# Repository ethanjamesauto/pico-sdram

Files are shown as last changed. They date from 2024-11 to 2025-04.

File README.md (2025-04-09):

# pico-sdram

This project attempts to interface a Raspberry Pi Pico with a [32MB SDRAM IC](https://www.winbond.com/resource-files/w9825g6kh_a04.pdf).

<p>
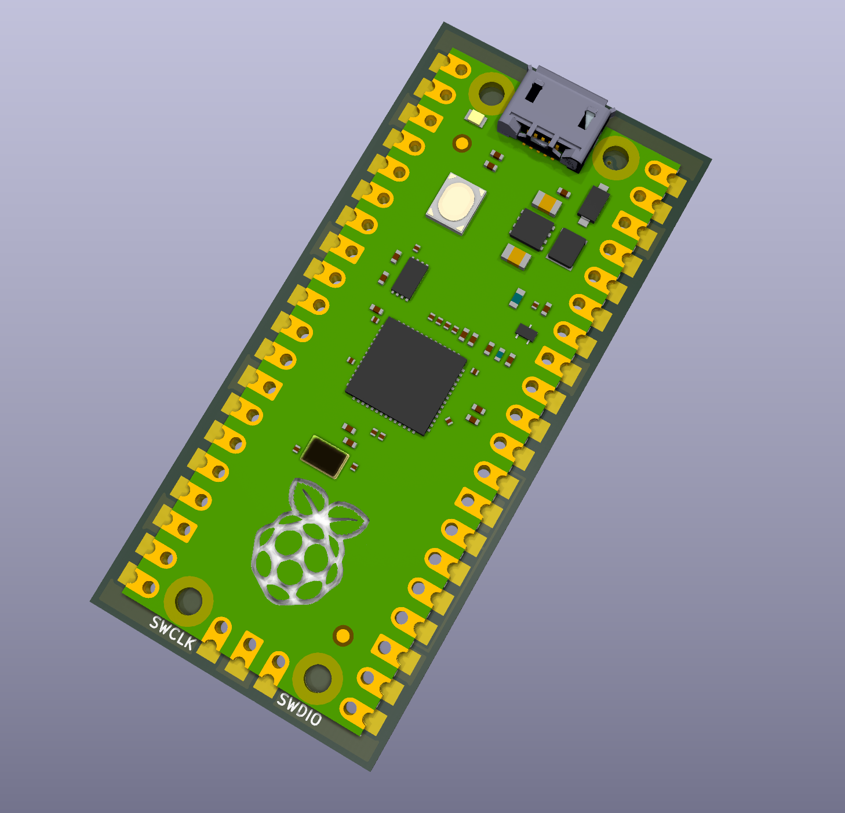
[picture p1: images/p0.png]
  
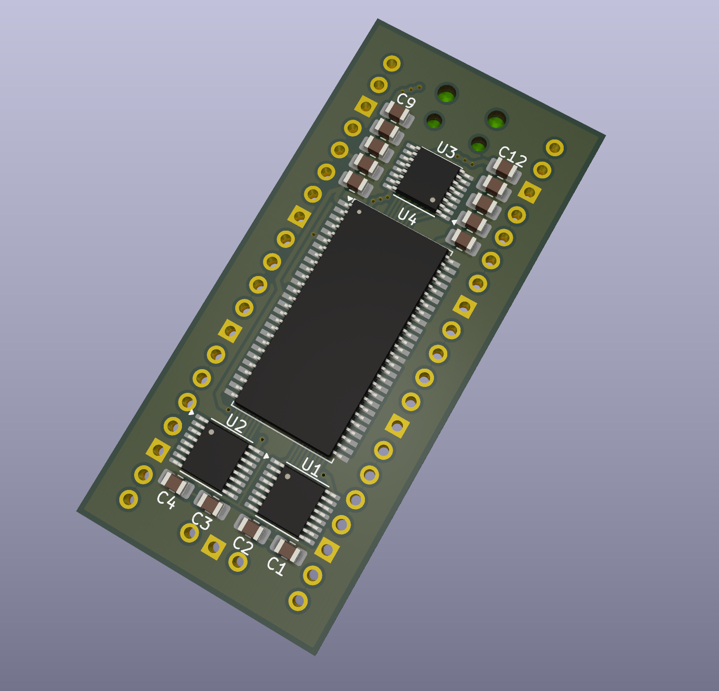
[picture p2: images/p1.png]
   
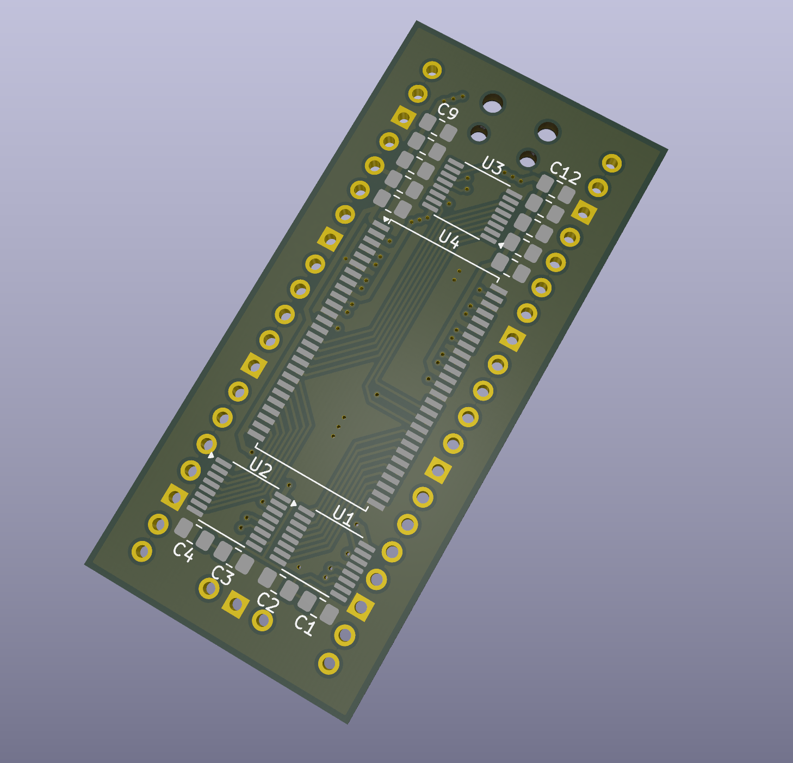
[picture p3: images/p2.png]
  
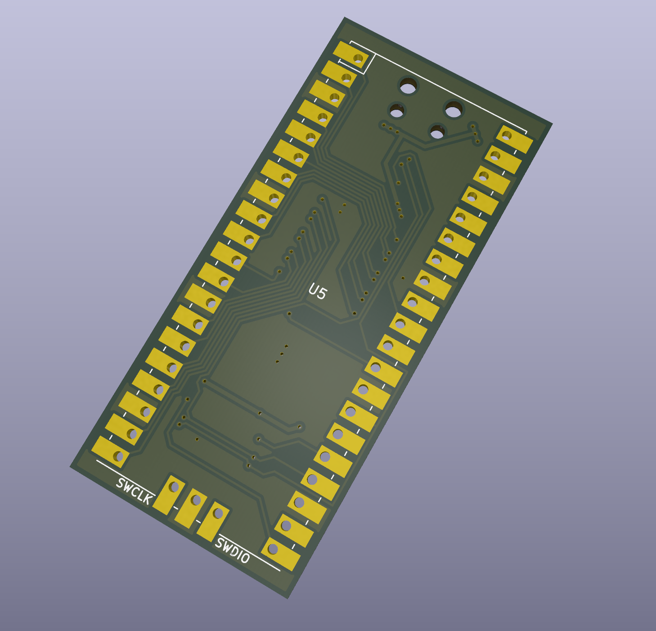
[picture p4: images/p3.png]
  
</p>

## UPDATE - Current State
I have been able to successfully perform single and burst read/writes to the W9825G6KH SDRAM IC. I am running the SDRAM at half the speed of the rp2040 clock - the PIO state machines
are running at the minimum clock divider value.
I don't have full documentation, but some is available in:
* [pico/src/sdram_cmd.c](pico/src/sdram_cmd.c) - contains the main driver code
* [pico/src/pico-sdram.c](pico/src/pico-sdram.c) - example usage of the driver code
* [pico/src/three_74hc595.pio](pico/src/three_74hc595.pio) - PIO driver for the 3x 74hc595 shift registers used to drive the address bus
* [pico/src/data_bus.pio](pico/src/data_bus.pio) - PIO driver for the 16-bit data bus

## Introduction
SDRAM ICs are commonly available in sizes of up to 256MBit (32MB), and most have either an 8-bit or 16-bit data bus width. The control interface uses a total of 23 pins, so there are simply too many pins for an RP2040 to directly drive using GPIOs. 

Shift registers may be reduce the number of GPIOs needed to interface with the ram. Because the RP2040 can only drive shift registers so quickly, the SDRAM chip would need to be driven at a lower clock speed. I propose a solution in which the control pins are driven using shift registers while the data bus is connected directly to the RP2040's GPIOs. This reduces the speed at which commands can be sent to the SDRAM, while still allowing the data bus to run at full speed. This solution has a drawback - it takes more time to send the two commands needed to initiate a read (row activate and read). However, this issue becomes neglible when most reads and writes use large block sizes (for example, when performing 1KB block reads and writes).

## Future Work
Eventually, I'd like to use this SDRAM interface with a PIO-based QSPI interface. The QSPI interface may then appear as a QSPI PSRAM and can be connected to the rp2350's QSPI bus. The pico can then translate "psram" accesses to sdram accesses, which would **allow the pico to natively access sdram in the address space**. This might not be possible.

## Digilent Waveforms SDRAM Protocol Decoder
```js
// rgData: input, raw digital data array
// rgValue: output, decoded data array
// rgFlag: output, decoded flag array

c = rgData.length

for(var i = 0; i < c; i++){
   // take 4 least significant bits
   rgValue[i] = rgData[i] & 0xFF;
   // set flag other than zero for valid data
   rgFlag[i] = 1;
}

// value: value sample
// flag: flag sample
function Value2Text(flag, value) {
  var lower = value & 0xf;
  var addr10 = ((value >> 7) & 1) > 0;
  if (lower & 1) return "";
  if (lower == 14) return "NOP";
  if (lower == 6) return "BURST_TERM";
  if (lower == 10) return addr10 ? "READ_PRECHARGE" : "READ";
  if (lower == 2) return addr10 ? "WRITE_PRECHARGE" : "WRITE";
  if (lower == 12) return "ACTIVATE";
  if (lower == 4) return "PRECHARGE";
  if (lower == 8) return "AUTO_REFRESH";
  if (lower == 0) return "LOAD_MODE";
  return "X";
}
Value2Text(0,0x82)

function Value2Text(flag, value) {
  var lower = value & 0xf;
  var addr10 = ((value >> 7) & 1) > 0;
  if (lower & 1) return "";
  if (lower == 14) return "NOP";
  if (lower == 6) return "BURST_T";
  if (lower == 10) return addr10 ? "READ_P" : "READ";
  if (lower == 2) return addr10 ? "WRITE_P" : "WRITE";
  if (lower == 12) return "ACTIVATE";
  if (lower == 4) return "PRCHG";
  if (lower == 8) return "A_RFRSH";
  if (lower == 0) return "MODE";
  return "X";
}
```

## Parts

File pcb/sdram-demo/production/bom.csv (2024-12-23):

Designator | Footprint | Quantity | Value | LCSC Part #
C1, C4 | 0805 | 2 | 2.2u
C2, C3 | 0805 | 2 | 100n
JP1 | SolderJumper-2_P1.3mm_Open_Pad1.0x1.5mm | 1 | Jumper_2_Open
U1, U2, U3 | SOIC-16_3.9x9.9mm_P1.27mm | 3 | 74HC595
U4 | TSOP-II-54_22.2x10.16mm_P0.8mm | 1 | MT48LC16M16A2P
U5 | RPi_Pico_SMD_TH | 1 | Pico

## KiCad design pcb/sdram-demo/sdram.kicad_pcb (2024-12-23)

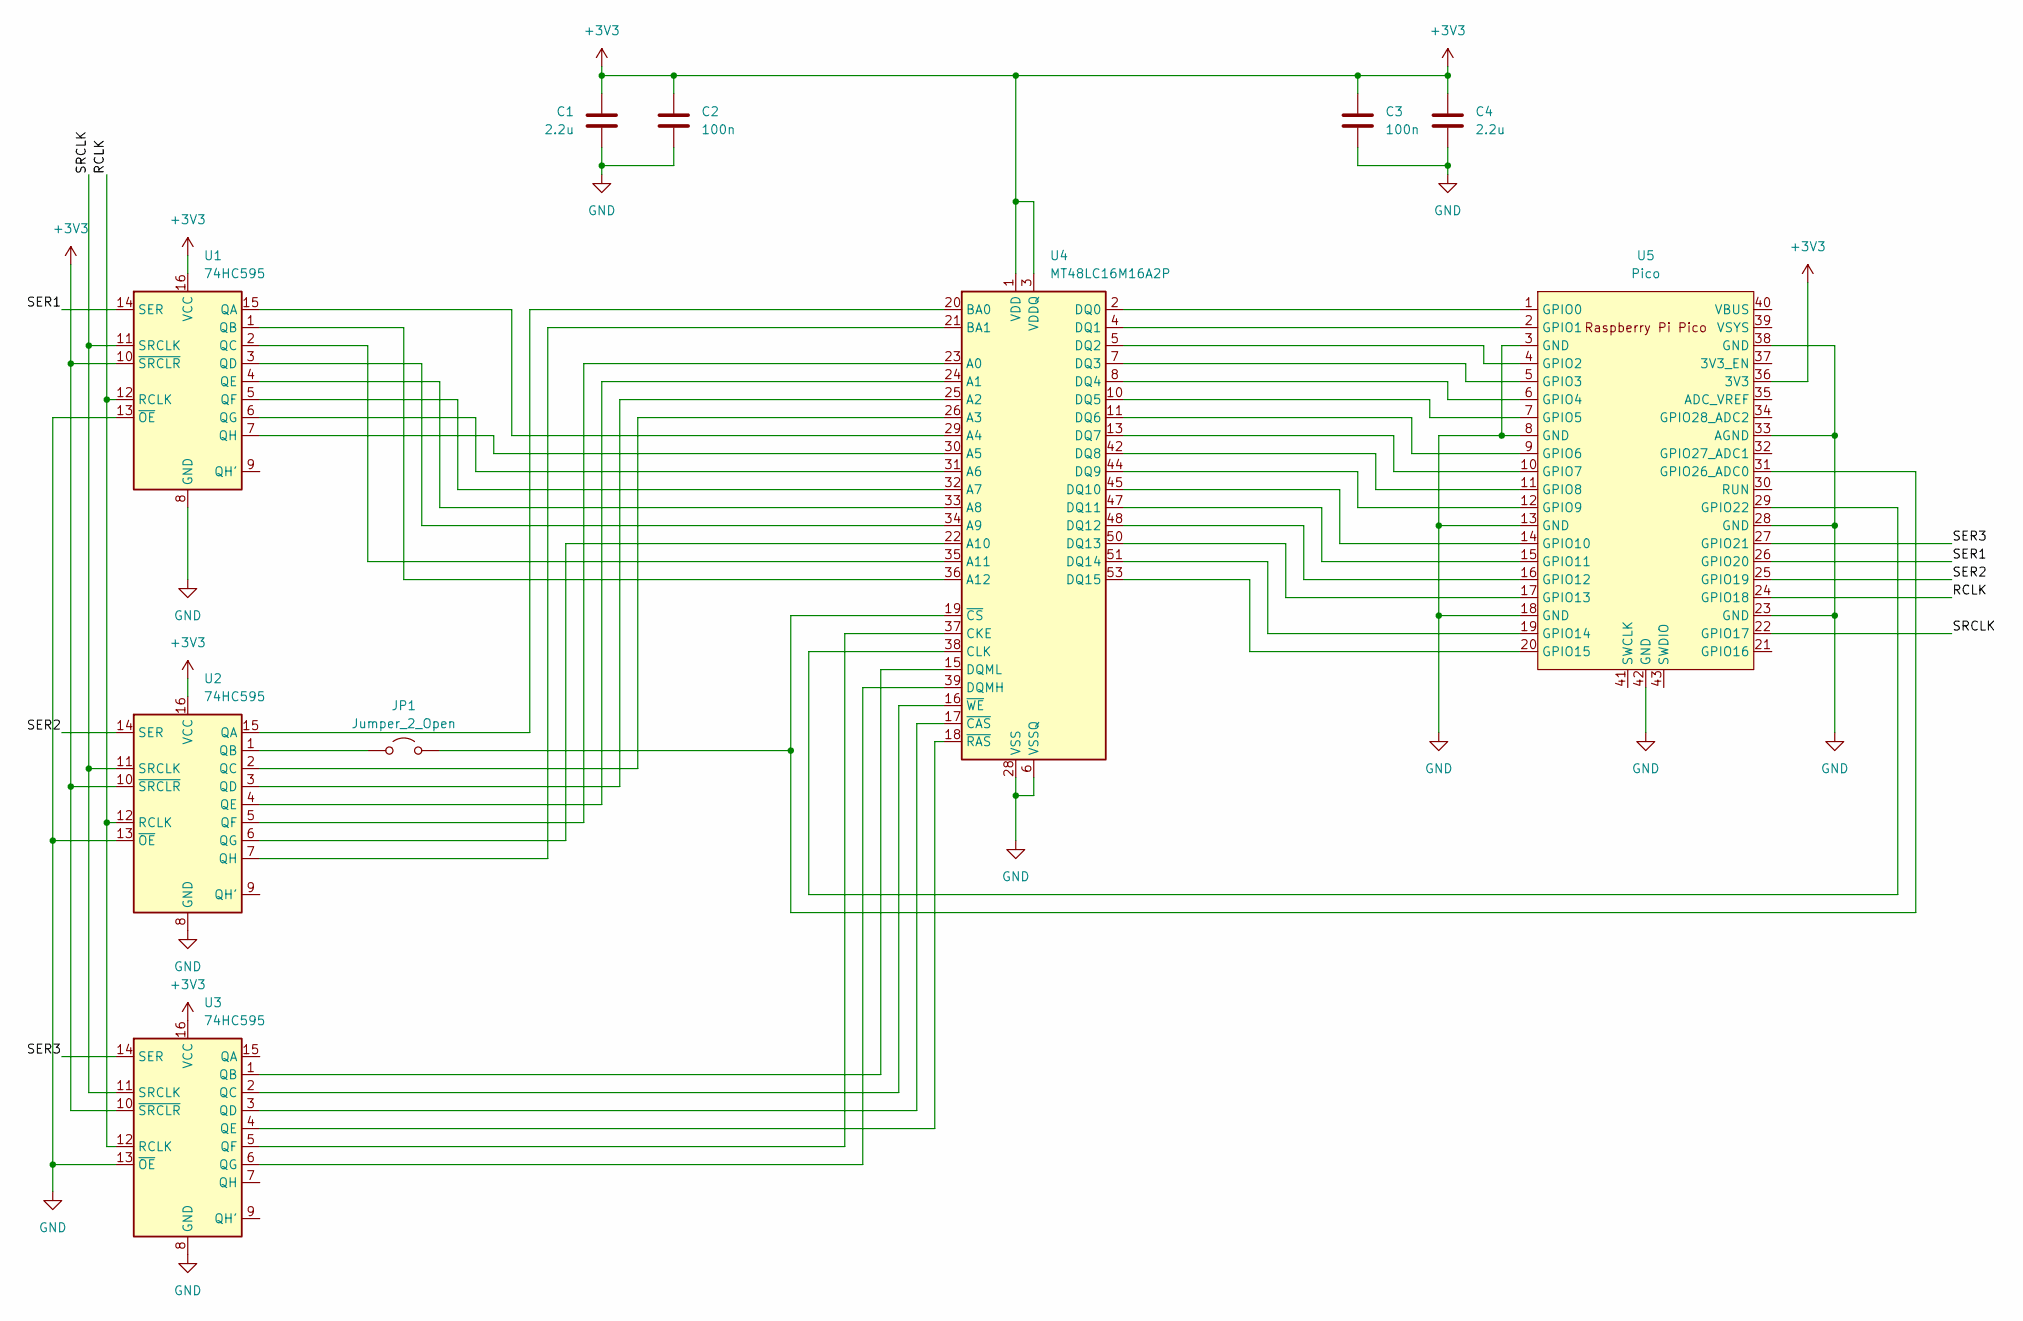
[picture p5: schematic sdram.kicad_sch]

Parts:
C1, C4: 2.2u; C_0805_2012Metric_Pad1.18x1.45mm_HandSolder
C2, C3: 100n; C_0805_2012Metric_Pad1.18x1.45mm_HandSolder
JP1: Jumper_2_Open; SolderJumper-2_P1.3mm_Open_Pad1.0x1.5mm
U1, U2, U3: 74HC595; SOIC-16_3.9x9.9mm_P1.27mm
U4: MT48LC16M16A2P; TSOP-II-54_22.2x10.16mm_P0.8mm
U5: Pico; RPi_Pico_SMD_TH

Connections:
+3V3: C1.1, C2.1, C3.1, C4.1, U1.10 (~SRCLR), U1.16 (VCC), U2.10 (~SRCLR), U2.16 (VCC), U3.10 (~SRCLR), U3.16 (VCC), U4.1 (VDD), U4.3 (VDDQ), U4.9 (VDDQ), U4.14 (VDD), U4.27 (VDD), U4.43 (VDDQ), U4.49 (VDDQ), U5.36 (3V3)
/RCLK: U1.12 (RCLK), U2.12 (RCLK), U3.12 (RCLK), U5.24 (GPIO18)
/SER1: U1.14 (SER), U5.26 (GPIO20)
/SER2: U2.14 (SER), U5.25 (GPIO19)
/SER3: U3.14 (SER), U5.27 (GPIO21)
/SRCLK: U1.11 (SRCLK), U2.11 (SRCLK), U3.11 (SRCLK), U5.22 (GPIO17)
GND: C1.2, C2.2, C3.2, C4.2, U1.8 (GND), U1.13 (~OE), U2.8 (GND), U2.13 (~OE), U3.8 (GND), U3.13 (~OE), U4.6 (VSSQ), U4.12 (VSSQ), U4.28 (VSS), U4.41 (VSS), U4.46 (VSSQ), U4.52 (VSSQ), U4.54 (VSS), U5.3 (GND), U5.8 (GND), U5.13 (GND), U5.18 (GND), U5.23 (GND), U5.28 (GND), U5.33 (AGND), U5.38 (GND), U5.42 (GND)
unnamed: JP1.1 (A), U2.1 (QB)
unnamed: JP1.2 (B), U4.19 (~CS), U5.31 (GPIO26_ADC0)
unnamed: U1.15 (QA), U4.29 (A4)
unnamed: U1.1 (QB), U4.36 (A12)
unnamed: U1.2 (QC), U4.35 (A11)
unnamed: U1.3 (QD), U4.34 (A9)
unnamed: U1.4 (QE), U4.33 (A8)
unnamed: U1.5 (QF), U4.32 (A7)
unnamed: U1.6 (QG), U4.31 (A6)
unnamed: U1.7 (QH), U4.30 (A5)
unnamed: U2.15 (QA), U4.20 (BA0)
unnamed: U2.2 (QC), U4.26 (A3)
unnamed: U2.3 (QD), U4.25 (A2)
unnamed: U2.4 (QE), U4.24 (A1)
unnamed: U2.5 (QF), U4.23 (A0)
unnamed: U2.6 (QG), U4.22 (A10)
unnamed: U2.7 (QH), U4.21 (BA1)
unnamed: U3.1 (QB), U4.15 (DQML)
unnamed: U3.2 (QC), U4.16 (~WE)
unnamed: U3.3 (QD), U4.17 (~CAS)
unnamed: U3.4 (QE), U4.18 (~RAS)
unnamed: U3.5 (QF), U4.37 (CKE)
unnamed: U3.6 (QG), U4.39 (DQMH)
unnamed: U4.38 (CLK), U5.29 (GPIO22)
unnamed: U4.2 (DQ0), U5.1 (GPIO0)
unnamed: U4.4 (DQ1), U5.2 (GPIO1)
unnamed: U4.5 (DQ2), U5.4 (GPIO2)
unnamed: U4.7 (DQ3), U5.5 (GPIO3)
unnamed: U4.8 (DQ4), U5.6 (GPIO4)
unnamed: U4.10 (DQ5), U5.7 (GPIO5)
unnamed: U4.11 (DQ6), U5.9 (GPIO6)
unnamed: U4.13 (DQ7), U5.10 (GPIO7)
unnamed: U4.42 (DQ8), U5.11 (GPIO8)
unnamed: U4.44 (DQ9), U5.12 (GPIO9)
unnamed: U4.45 (DQ10), U5.14 (GPIO10)
unnamed: U4.47 (DQ11), U5.15 (GPIO11)
unnamed: U4.48 (DQ12), U5.16 (GPIO12)
unnamed: U4.50 (DQ13), U5.17 (GPIO13)
unnamed: U4.51 (DQ14), U5.19 (GPIO14)
unnamed: U4.53 (DQ15), U5.20 (GPIO15)

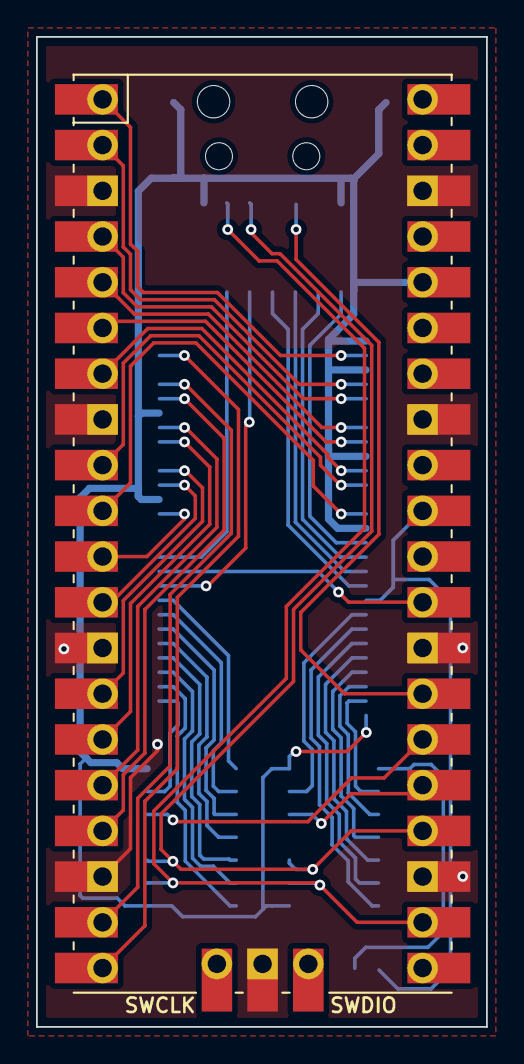
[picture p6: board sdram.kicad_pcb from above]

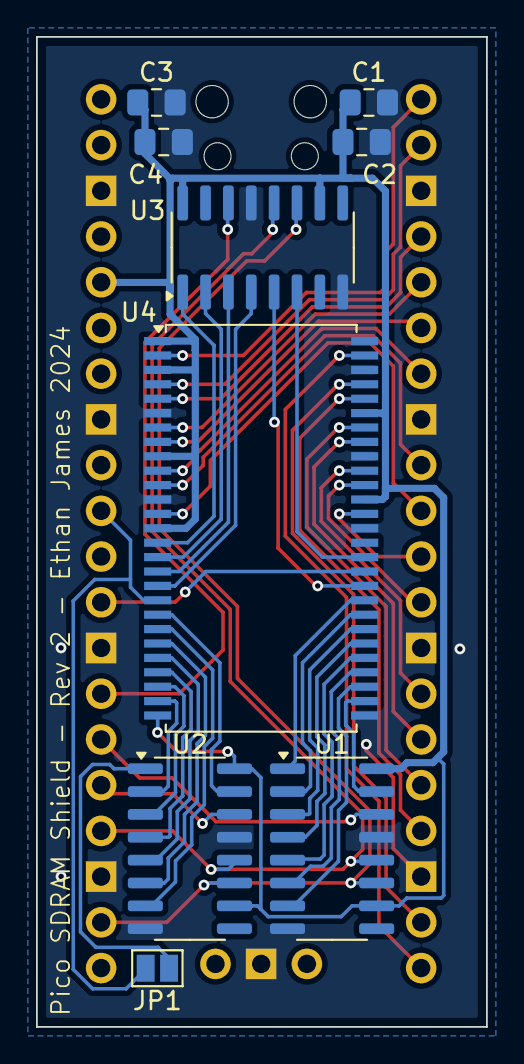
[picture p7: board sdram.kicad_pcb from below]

Board: 2 copper layers, 25.0 x 55.0 mm, 10 parts (9 on the bottom side), 47 nets.

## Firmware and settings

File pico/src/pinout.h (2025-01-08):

// #define CONFIG_DEBUG
// #define CONFIG_REV1
#define CONFIG_REV2

// On rev 2.0, the CS pin is also connected to this gpio.
// Right now, I'm using the CS pin on the shift register, so this pin should be set to high impedance.
#define SDRAM_CS 26


#ifdef CONFIG_DEBUG

// shift register 1
#define PIN_SDRAM_CS (1 << 0*3)
#define PIN_SDRAM_RAS (1 << 1*3)
#define PIN_SDRAM_CAS (1 << 2*3)
#define PIN_SDRAM_WE (1 << 3*3)
#define PIN_SDRAM_CKE (1 << 4*3)
#define PIN_SDRAM_DQML (1 << 5*3)
#define PIN_SDRAM_DQMH (1 << 6*3)
#define PIN_SDRAM_ADDR10 (1 << 7*3)

// shift register 2
#define PIN_SDRAM_ADDR8 (2 << 0*3)
#define PIN_SDRAM_ADDR9 (2 << 1*3)
// #define PIN_SDRAM_ADDR10 (2 << 2*3)
#define PIN_SDRAM_ADDR11 (2 << 3*3)
#define PIN_SDRAM_ADDR12 (2 << 4*3)
#define PIN_SDRAM_BA0 (2 << 5*3)
#define PIN_SDRAM_BA1 (2 << 6*3)

// shift register 3
#define PIN_SDRAM_ADDR0 (4 << 0*3)
#define PIN_SDRAM_ADDR1 (4 << 1*3)
#define PIN_SDRAM_ADDR2 (4 << 2*3)
#define PIN_SDRAM_ADDR3 (4 << 3*3)
#define PIN_SDRAM_ADDR4 (4 << 4*3)
#define PIN_SDRAM_ADDR5 (4 << 5*3)
#define PIN_SDRAM_ADDR6 (4 << 6*3)
#define PIN_SDRAM_ADDR7 (4 << 7*3)



#define DATA_BASE 0
#define DATA_WIDTH 16

#define CMD_SM_TOTAL_PINS 5
#define CMD_SM_SHIFT_OUT_BASE 19
#define CMD_SM_SIDESET_BASE 17

// This value is also hardcoded in the PIO state machines
// TODO: make this not the case
#define SDRAM_CLK 22

#elif defined(CONFIG_REV1)
// PCB Rev 1.0 pinout
// Note for 74hc595:
// A - 0
// B - 1
// C - 2
// D - 3
// E - 4
// F - 5
// G - 6
// H - 7

// shift register 3 (SER3)
#define PIN_SDRAM_DQML (4 << 0*3)
#define PIN_SDRAM_DQMH (4 << 1*3)
#define PIN_SDRAM_CKE (4 << 2*3)
#define PIN_SDRAM_CS (4 << 3*3)
#define PIN_SDRAM_RAS (4 << 4*3)
#define PIN_SDRAM_CAS (4 << 5*3)
#define PIN_SDRAM_WE (4 << 6*3)

// shift register 2 (SER2)
#define PIN_SDRAM_BA0 (1 << 0*3)

#define PIN_SDRAM_ADDR3 (1 << 2*3)
#define PIN_SDRAM_ADDR2 (1 << 3*3)
#define PIN_SDRAM_ADDR1 (1 << 4*3)
#define PIN_SDRAM_ADDR0 (1 << 5*3)
#define PIN_SDRAM_ADDR10 (1 << 6*3)
#define PIN_SDRAM_BA1 (1 << 7*3)

// shift register 1 (SER1)

#define PIN_SDRAM_ADDR4 (2 << 0*3)
#define PIN_SDRAM_ADDR12 (2 << 1*3)
#define PIN_SDRAM_ADDR11 (2 << 2*3)
#define PIN_SDRAM_ADDR9 (2 << 3*3)
#define PIN_SDRAM_ADDR8 (2 << 4*3)
#define PIN_SDRAM_ADDR7 (2 << 5*3)
#define PIN_SDRAM_ADDR6 (2 << 6*3)
#define PIN_SDRAM_ADDR5 (2 << 7*3)
// #define PIN_SDRAM_ADDR10 (2 << 2*3)



#define DATA_BASE 0
#define DATA_WIDTH 16

#define CMD_SM_TOTAL_PINS 5
#define CMD_SM_SHIFT_OUT_BASE 19
#define CMD_SM_SIDESET_BASE 18

// This value is also hardcoded in the PIO state machines
// TODO: make this not the case
#define SDRAM_CLK 22

#else

// PCB Rev 2.0 pinout
// Note for 74hc595:
// A - 0
// B - 1
// C - 2
// D - 3
// E - 4
// F - 5
// G - 6
// H - 7

// shift register 3 (SER3)
// #define NOT_USED (4 << 0*3)
#define PIN_SDRAM_DQML (4 << 1*3)
#define PIN_SDRAM_WE (4 << 2*3)
#define PIN_SDRAM_CAS (4 << 3*3)
#define PIN_SDRAM_RAS (4 << 4*3)
#define PIN_SDRAM_CKE (4 << 5*3)
#define PIN_SDRAM_DQMH (4 << 6*3)
// #define NOT_USED (4 << 7*3)

// shift register 2 (SER2)
#define PIN_SDRAM_BA0 (1 << 0*3)
#define PIN_SDRAM_CS (1 << 1*3)
#define PIN_SDRAM_ADDR3 (1 << 2*3)
#define PIN_SDRAM_ADDR2 (1 << 3*3)
#define PIN_SDRAM_ADDR1 (1 << 4*3)
#define PIN_SDRAM_ADDR0 (1 << 5*3)
#define PIN_SDRAM_ADDR10 (1 << 6*3)
#define PIN_SDRAM_BA1 (1 << 7*3)

// shift register 1 (SER1)

#define PIN_SDRAM_ADDR4 (2 << 0*3)
#define PIN_SDRAM_ADDR12 (2 << 1*3)
#define PIN_SDRAM_ADDR11 (2 << 2*3)
#define PIN_SDRAM_ADDR9 (2 << 3*3)
#define PIN_SDRAM_ADDR8 (2 << 4*3)
#define PIN_SDRAM_ADDR7 (2 << 5*3)
#define PIN_SDRAM_ADDR6 (2 << 6*3)
#define PIN_SDRAM_ADDR5 (2 << 7*3)


#define DATA_BASE 0
#define DATA_WIDTH 16

#define CMD_SM_TOTAL_PINS 5
#define CMD_SM_SHIFT_OUT_BASE 19
#define CMD_SM_SIDESET_BASE 18

// This value is also hardcoded in the PIO state machines
// TODO: make this not the case
#define SDRAM_CLK 22

#endif

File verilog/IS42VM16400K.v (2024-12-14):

/************************************************************************
*
* Copyright(c) ISSI Inc., 2010
*
* == 64M Low power SDRAM behavioral Model by ESC ==
*
* Address : 1940 Zanker Road San Jose,CA95112-4216,U.S.A.
* Tel : +1-408-969-6600, Fax : +1-408-969-7800
*
* Revision : Rev0.0 (2010.10.4)
*
* Running Options
*  +S50     : Set AC timing parameter for -50(200MHz  )
*  +S60     : Set AC timing parameter for -60(166MHz  )
*  +S75     : Set AC timing parameter for -75(133MHz  )
*  +VERBOSE : Display internal operation status
*
************************************************************************/

`timescale 1ns / 1ps

`define S60
`define VERBOSE

    module IS42VM16400K (dq, addr, ba, clk, cke, csb, rasb, casb, web, dqm);

    parameter no_of_bank =       2;
    parameter no_of_addr =      13;
    parameter no_of_data =      16;
    parameter no_of_col  =       9;
    parameter no_of_dqm  =       2;
    parameter mem_sizes  = 4194304;


    // Timing Parameters for -50 PC200 
    `ifdef S50
    parameter tAC3 =   5.0;
    parameter tHZ3 =   5.0;
    parameter tAC2 =   8.0;
    parameter tHZ2 =   8.0;
    parameter tOH  =   2.0;
    parameter tMRD =   2.0;
    parameter tRAS =  40.0;
    parameter tRC  =  55.0;
    parameter tRCD =  18.0;
    parameter tRFC =  60.0;
    parameter tXSR =  60.0;
    parameter tRP  =  15.0;
    parameter tRRD =  10.0;
    parameter tDPLa =  5.0;
    parameter tDPLm =  12.0;
    parameter tDPDX =  100000.0;
    `endif


    // Timing Parameters for -60 PC166 
    `ifdef S60
    parameter tAC3 =   5.5;
    parameter tHZ3 =   5.5;
    parameter tAC2 =   8.0;
    parameter tHZ2 =   8.0;
    parameter tOH  =   2.5;
    parameter tMRD =   2.0;     
    parameter tRAS =  42.0;
    parameter tRC  =  60.0;
    parameter tRCD =  18.0;
    parameter tRFC =  66.0;
    parameter tXSR =  66.0;
    parameter tRP  =  18.0;
    parameter tRRD =  12.0;
    parameter tDPLa =  6.0;     
    parameter tDPLm =  12.0;     
    parameter tDPDX =  100000.0;   
    `endif

    // Timing Parameters for -75 PC133 
    `ifdef S75
    parameter tAC3 =   6.0;
    parameter tHZ3 =   6.0;
    parameter tAC2 =   8.0;
    parameter tHZ2 =   8.0;
    parameter tOH  =   2.5;
    parameter tMRD =   2.0;    
    parameter tRAS =  45.0;
    parameter tRC  =  67.5;
    parameter tRCD =  22.5;
    parameter tRFC =  67.5;
    parameter tXSR =  67.5;
    parameter tRP  =  22.5;
    parameter tRRD =  15.0;
    parameter tDPLa =  7.5;  
    parameter tDPLm =  15.0; 
    parameter tDPDX =  100000.0;
    `endif


    inout     [no_of_data - 1 : 0] dq;
    input     [no_of_addr - 1 : 0] addr;
    input     [no_of_bank - 1 : 0] ba;
    input                         clk;
    input                         cke;
    input                         csb;
    input                         rasb;
    input                         casb;
    input                         web;
    input     [no_of_dqm - 1 : 0]  dqm;

`protect

    reg       [no_of_data - 1 : 0] bank0 [0 : mem_sizes];
    reg       [no_of_data - 1 : 0] bank1 [0 : mem_sizes];
    reg       [no_of_data - 1 : 0] bank2 [0 : mem_sizes];
    reg       [no_of_data - 1 : 0] bank3 [0 : mem_sizes];

    reg       [no_of_bank - 1 : 0] bank_addr [0 : 3];                 // bank address Pipeline
    reg       [no_of_col - 1 : 0] Col_addr [0 : 3];                 // Column address Pipeline
    reg                   [3 : 0] Command [0 : 3];                  // Command Operation Pipeline
    reg       [no_of_dqm - 1 : 0] dqm_reg0, dqm_reg1;               // DQM Operation Pipeline
    reg       [no_of_dqm - 1 : 0] dqm_save [0 : 3];                 // DQM Operation Pipeline
    reg       [no_of_addr - 1 : 0] B0_row_addr, B1_row_addr, B2_row_addr, B3_row_addr;

    reg       [no_of_addr - 1 : 0] Mode_reg;
    reg       [no_of_addr - 1 : 0] EMode_reg;
    reg       [no_of_data - 1 : 0] dq_reg, dq_dqm;
    reg        [no_of_col - 1 : 0] Col_temp, Burst_counter;

    reg                           Act_b0, Act_b1, Act_b2, Act_b3;    // bank Activate
    reg                           Pc_b0, Pc_b1, Pc_b2, Pc_b3;        // bank Precharge

    reg                   [1 : 0] bank_precharge       [0 : 3];     // Precharge Command
    reg                           A10_precharge        [0 : 3];     // addr[10] = 1 (All banks)
    reg                           Auto_precharge       [0 : 3];     // RW Auto Precharge (bank)
    reg                           Read_precharge       [0 : 3];     // R  Auto Precharge
    reg                           Write_precharge      [0 : 3];     //  W Auto Precharge
    reg                           RW_interrupt_read    [0 : 3];     // RW Interrupt Read with Auto Precharge
    reg                           RW_interrupt_write   [0 : 3];     // RW Interrupt Write with Auto Precharge
    reg                   [1 : 0] RW_interrupt_bank;                // RW Interrupt bank
    integer                       RW_interrupt_counter [0 : 3];     // RW Interrupt Counter
    integer                       Count_precharge      [0 : 3];     // RW Auto Precharge Counter

    reg                           Data_in_enable;
    reg                           Data_out_enable;

    reg       [no_of_bank - 1 : 0] bank, Prev_bank;
    reg       [no_of_addr - 1 : 0] Row;
    reg        [no_of_col - 1 : 0] Col, Col_brst;

    reg                 [19:0]    ccc;
    reg                 [3:0]     bit;
    reg                 [2:0]     CL;
    reg                 [8:0]     BL;
    reg             RIW_violate; 
    reg             Dout_Drive_Flag;
    reg             Pre_Dout_Drive_Flag;
    reg             [10:0] Count_at_Read;
    reg             Read_cmd_received;
    reg             Read_cmd_received_cke;
    reg             Write_cmd_received_cke;
    reg             state_act_pwrdn,state_pre_pwrdn,state_dpdn,state_self;
    reg             dpdn_check_start;
    reg             [10:0] Read_cmd_count;
    reg             [10:0] Read_cmd_count_cke;
    reg             [10:0] Write_cmd_count_cke;
    reg             [3:0] cmp_count;
    // Internal system clock
    reg                           ckeZ, Sys_clk;

    // Commands Decode
    wire      Active_enable    = ~csb & ~rasb &  casb &  web ;
    wire      Aref_enable      = ~csb & ~rasb & ~casb &  web & cke;
    wire      Sref_enable      = ~csb & ~rasb & ~casb &  web & ~cke;
    wire      Burst_term       = ~csb &  rasb &  casb & ~web & cke;
    wire      Deep_pwrdn       = ~csb &  rasb &  casb & ~web & ~cke;
    wire      Mode_reg_enable  = ~csb & ~rasb & ~casb & ~web & ~ba[1] & ~ba[0];
    wire      EMode_reg_enable = ~csb & ~rasb & ~casb & ~web & ba[1] & ~ba[0];
    wire      Prech_enable     = ~csb & ~rasb &  casb & ~web ;
    wire      Read_enable      = ~csb &  rasb & ~casb &  web ;
    wire      Write_enable     = ~csb &  rasb & ~casb & ~web ;
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

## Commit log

2024-11-23 Add PCB
    [sdram.kicad_pcb, sdram.kicad_sch]
2024-11-23 Update pcb
    [sdram.kicad_pcb, sdram.kicad_sch]
2024-11-23 Update pcb and add pio code
    [sdram.kicad_pcb, sdram.kicad_sch]
2024-11-24 Add pico software
2024-11-25 add data bus pio driver
2024-11-26 Add separate clkgen sm
    [sdram.kicad_pcb]
2024-11-27 Add two tests
    [sdram.kicad_pcb]
2024-11-28 Add power-up seqeunce
2024-11-30 wip - adding input mode on data bus
    [sdram.kicad_pcb]
2024-11-30 Add cmds spreadsheet
    [cmds.xlsx]
2024-12-01 move problems out of sight
    [sdram_cmd.c]
2024-12-01 add pinout from rev1 pcb
    [sdram.kicad_sch]
2024-12-14 Add verilog sim
    [xilinx-sd.csv]
2024-12-14 Update sim files
    [xilinx-sd.csv, xilinx-sd2.csv, xilinx-sd3.csv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]
2024-12-15 Fix read happening at wrong time for cas latency 3
    [sdram_cmd.c]
2024-12-22 Fix silly linker errors
    [sdram_cmd.c, sdram_cmd.h]
2024-12-23 Add rev2 PCB
    [bom.csv, designators.csv, positions.csv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]
2025-01-02 Add support for rev 2 board
2025-01-08 Switch to rev2 layout
2025-01-08 Memtest now prints out total # of successes and failures
2025-01-09 Update sim
    [new-thing.csv]
2025-01-09 Fix sdram_exec bug that disallowed data lengths longer than cmd lengths
    [sdram_cmd.c]
2025-01-09 Add some code for dma full page reads
2025-01-09 Add dma for cmd channel
2025-01-10 Add page writes with DMA
2025-01-10 Rework sm start logic a bit
    [sdram_cmd.c]
